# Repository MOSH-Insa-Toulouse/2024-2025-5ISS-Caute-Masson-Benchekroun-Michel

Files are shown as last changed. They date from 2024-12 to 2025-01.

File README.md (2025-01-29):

**Repository structure :**
- [LoRa\_module.ino](LoRa_module.ino) : Smart device code, from the logic for using the gas sensor, to the BLE and LoRa connectivity.
- [Shield\_Gas\_Sensor](Shield_Gas_Sensor) : Design of the Arduino UNO shield for the smart device. See the routing [here](Shield_Gas_Sensor/Acquisition_board_aduino_UNO.kicad_pcb), and the schematic [here](Shield_Gas_Sensor/Acquisition_board_aduino_UNO.kicad_sch)
- [Node-RED](Node-RED) : Node RED application code
- [Documentation](Documentation) : Datasheet of the used components
- [The datasheet](Datasheet_Gas_Sensor.pdf) : Datasheet of our gas sensor
- [The project report](MOSH_Report.pdf) : Report of our smart device project, from the manufacturing of the MOx sensor to the design of our node PCB, sensor conditionner and application

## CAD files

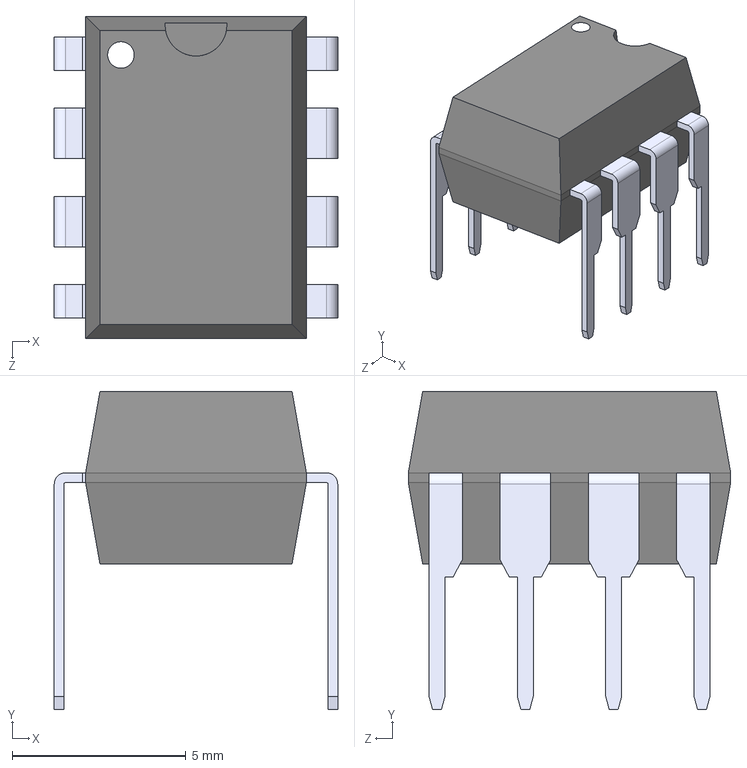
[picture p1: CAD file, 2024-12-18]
Shield_Gas_Sensor/Gas_Sensor_lib/LTC1050ACN8_PBF/LTC1050ACN8_PBF.step
8.15 x 9.14 x 9.27 mm

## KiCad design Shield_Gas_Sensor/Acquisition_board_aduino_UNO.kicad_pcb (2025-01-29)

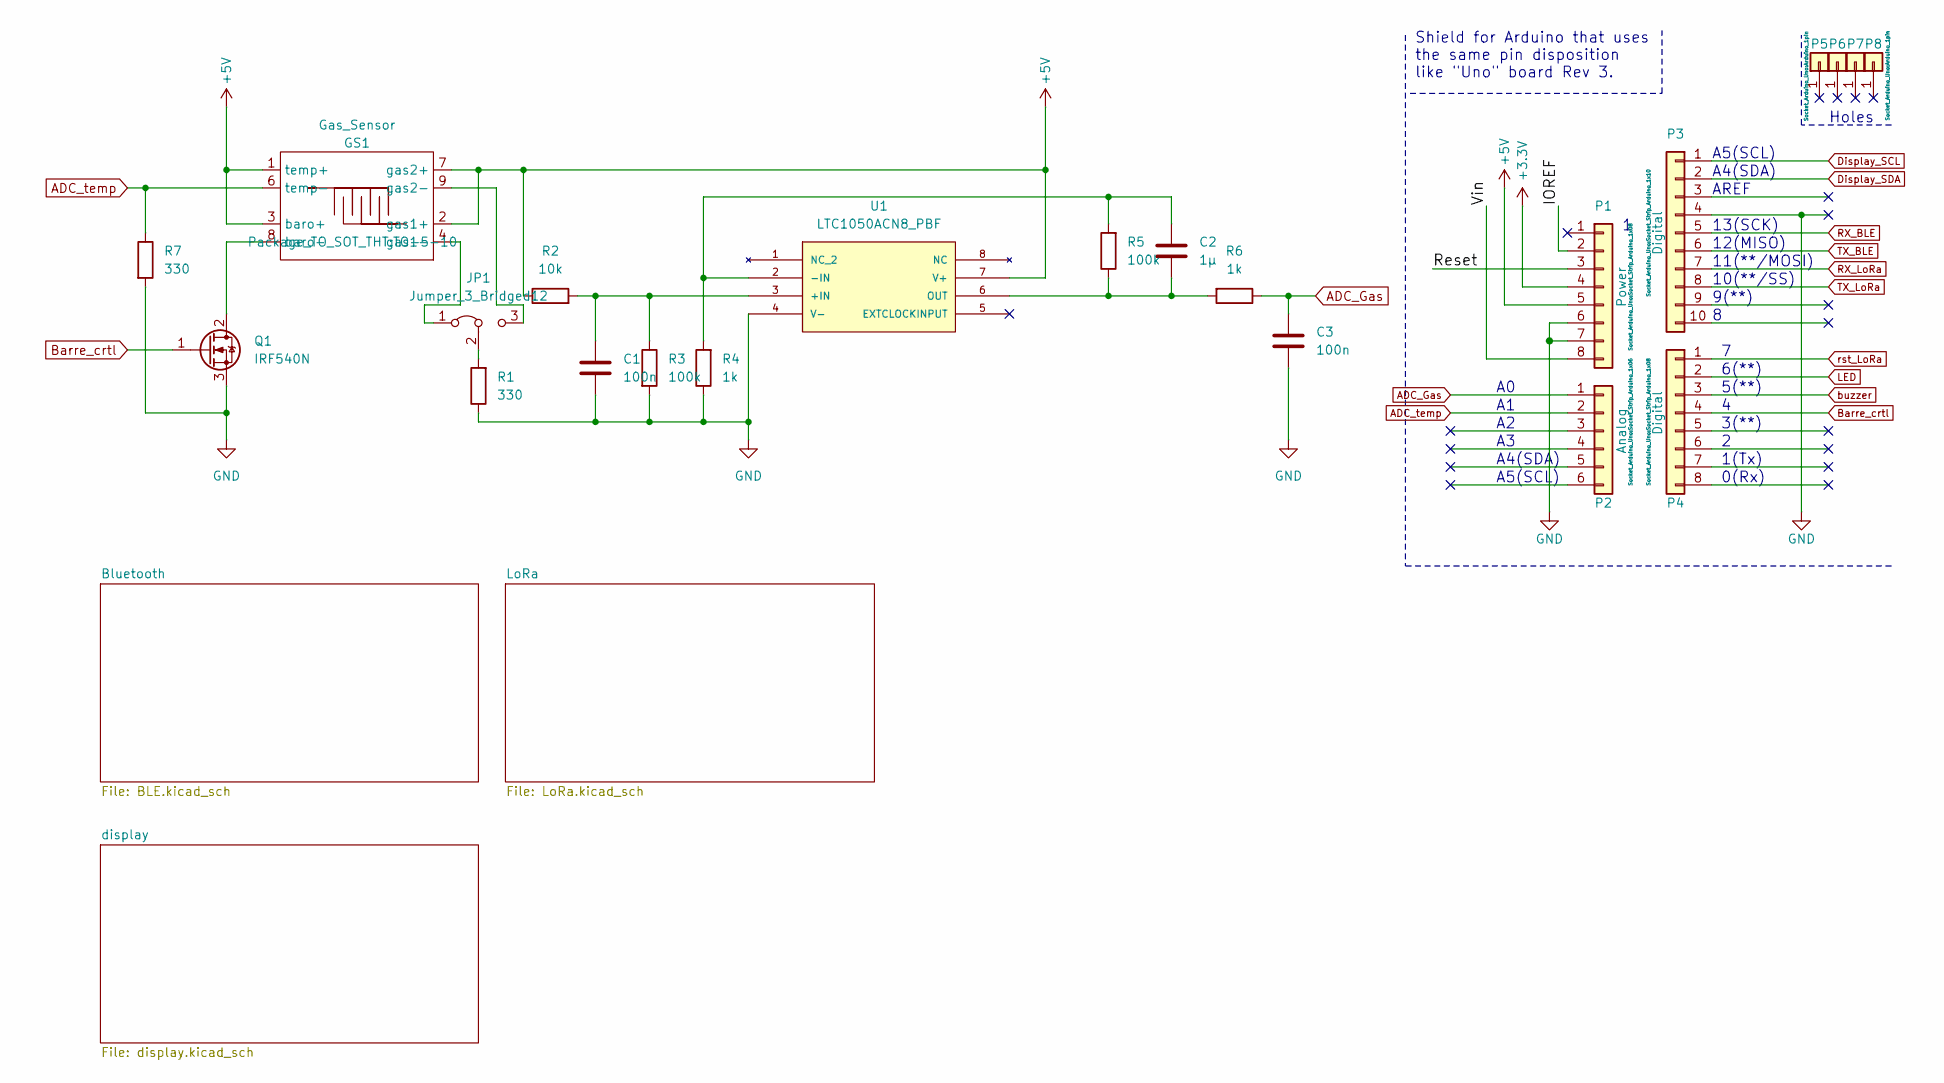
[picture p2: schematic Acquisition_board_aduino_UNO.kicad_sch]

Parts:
C1, C3: 100n; C_Disc_D3.0mm_W1.6mm_P2.50mm
C2: 1µ; C_Rect_L9.0mm_W3.6mm_P7.50mm_MKT
GS1: Gas_Sensor; TO-5-10
JP1: Jumper_3_Bridged12; PinSocket_1x03_P2.54mm_Vertical
P1: Power; Socket_Strip_Arduino_1x08
P2: Analog; Socket_Strip_Arduino_1x06
P3: Digital; Socket_Strip_Arduino_1x10
P4: Digital; Socket_Strip_Arduino_1x08
P5, P6, P7, P8: CONN_01X01; Arduino_1pin
Q1: IRF540N; TO-220-3_Vertical
R1, R7: 330; R_Axial_DIN0204_L3.6mm_D1.6mm_P2.54mm_Vertical
R2: 10k; R_Axial_DIN0204_L3.6mm_D1.6mm_P2.54mm_Vertical
R3, R5: 100k; R_Axial_DIN0204_L3.6mm_D1.6mm_P2.54mm_Vertical
R4, R6: 1k; R_Axial_DIN0204_L3.6mm_D1.6mm_P2.54mm_Vertical
U1: LTC1050ACN8_PBF; DIP-8_W7.62mm; MANUFACTURER_PART_NUMBER ltc1050acn8

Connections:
+3V3: P1.4
+5V: GS1.1 (temp+), GS1.2 (gas1+), GS1.3 (baro+), GS1.7 (gas2+), P1.5, R2.1, U1.7 (V+); also elsewhere on the board
/IOREF: P1.2
/Reset: P1.3
/Vin: P1.8
ADC_Gas: C3.1, P2.1, R6.1
ADC_temp: GS1.6 (temp-), P2.2, R7.1
Barre_crtl: P4.4, Q1.1 (G)
Display_SCL: P3.1; also elsewhere on the board
Display_SDA: P3.2; also elsewhere on the board
GND: C1.2, C3.2, P1.6, P1.7, P3.4, P5.1, P6.1, P7.1, P8.1, Q1.3 (S), R1.1, R3.2, R4.1, R7.2, U1.4 (V-); also elsewhere on the board
LED: P4.2; also elsewhere on the board
unnamed: C1.1, R2.2, R3.1, U1.3 (+IN)
unnamed: C2.1, R4.2, R5.2, U1.2 (-IN)
unnamed: C2.2, R5.1, R6.2, U1.6 (OUT)
unnamed: GS1.4 (gas1-), JP1.1 (A)
unnamed: GS1.8 (baro-), Q1.2 (D)
unnamed: GS1.9 (gas2-), JP1.3 (B)
unnamed: JP1.2 (C), R1.2
RX_BLE: P3.5; also elsewhere on the board
RX_LoRa: P3.7; also elsewhere on the board
TX_BLE: P3.6; also elsewhere on the board
TX_LoRa: P3.8; also elsewhere on the board
buzzer: P4.3; also elsewhere on the board
rst_LoRa: P4.1; also elsewhere on the board

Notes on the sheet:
A5(SCL)
6(**)
10(**/SS)
3(**)
0(Rx)
9(**)
Holes
1(Tx)
Shield for Arduino that uses the same pin disposition like "Uno" board Rev 3.
5(**)
12(MISO)
A4(SDA)
AREF
13(SCK)
11(**/MOSI)

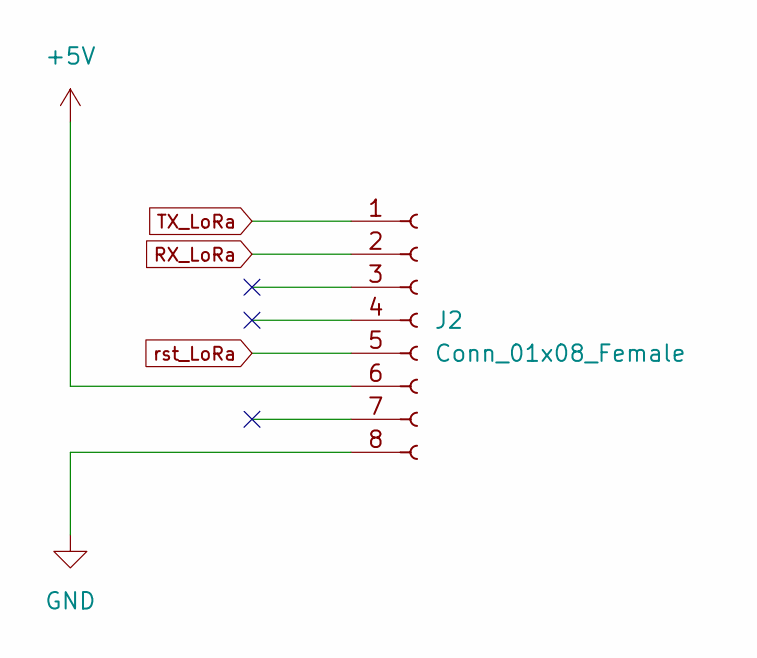
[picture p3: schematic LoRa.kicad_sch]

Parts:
J2: Conn_01x08_Female; PinSocket_1x08_P2.54mm_Vertical

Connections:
+5V: J2.6; also elsewhere on the board
GND: J2.8; also elsewhere on the board
RX_LoRa: J2.2; also elsewhere on the board
TX_LoRa: J2.1; also elsewhere on the board
rst_LoRa: J2.5; also elsewhere on the board

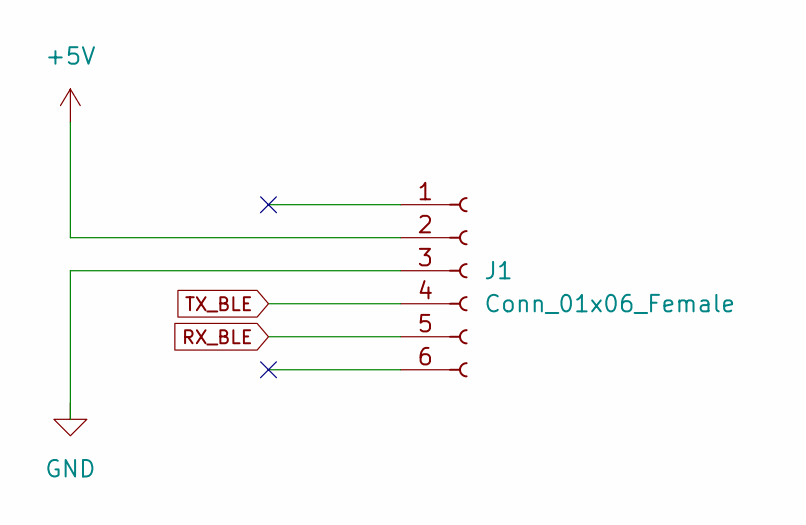
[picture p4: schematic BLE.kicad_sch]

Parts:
J1: Conn_01x06_Female; PinSocket_1x06_P2.54mm_Vertical

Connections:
+5V: J1.2; also elsewhere on the board
RX_BLE: J1.5; also elsewhere on the board
TX_BLE: J1.4; also elsewhere on the board

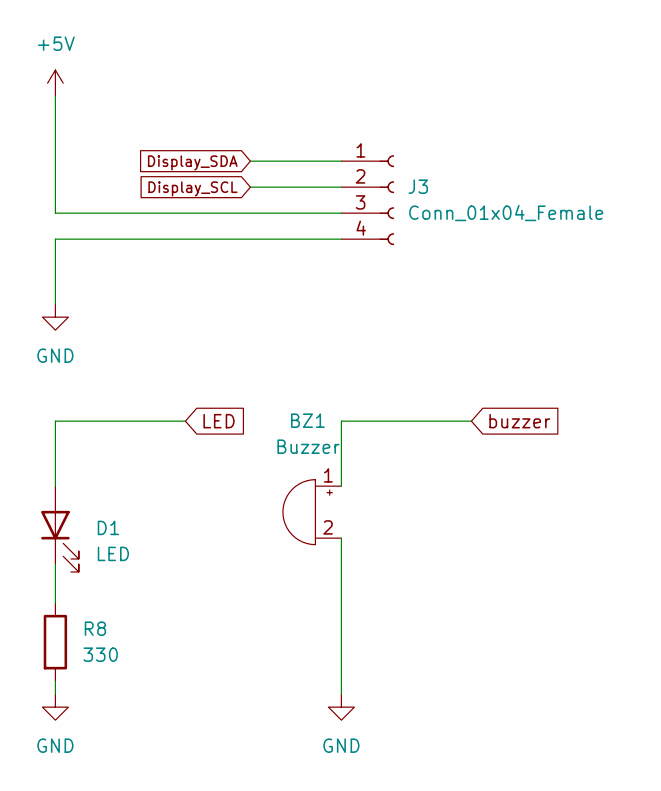
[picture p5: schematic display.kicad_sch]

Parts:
BZ1: Buzzer; Buzzer_TDK_PS1240P02BT_D12.2mm_H6.5mm
D1: LED; LED_D3.0mm
J3: Conn_01x04_Female; PinSocket_1x04_P2.54mm_Vertical
R8: 330; R_Axial_DIN0204_L3.6mm_D1.6mm_P2.54mm_Vertical

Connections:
+5V: J3.3; also elsewhere on the board
Display_SCL: J3.2; also elsewhere on the board
Display_SDA: J3.1; also elsewhere on the board
GND: BZ1.2 (+), J3.4, R8.2; also elsewhere on the board
LED: D1.2 (A); also elsewhere on the board
unnamed: D1.1 (K), R8.1
buzzer: BZ1.1 (-); also elsewhere on the board

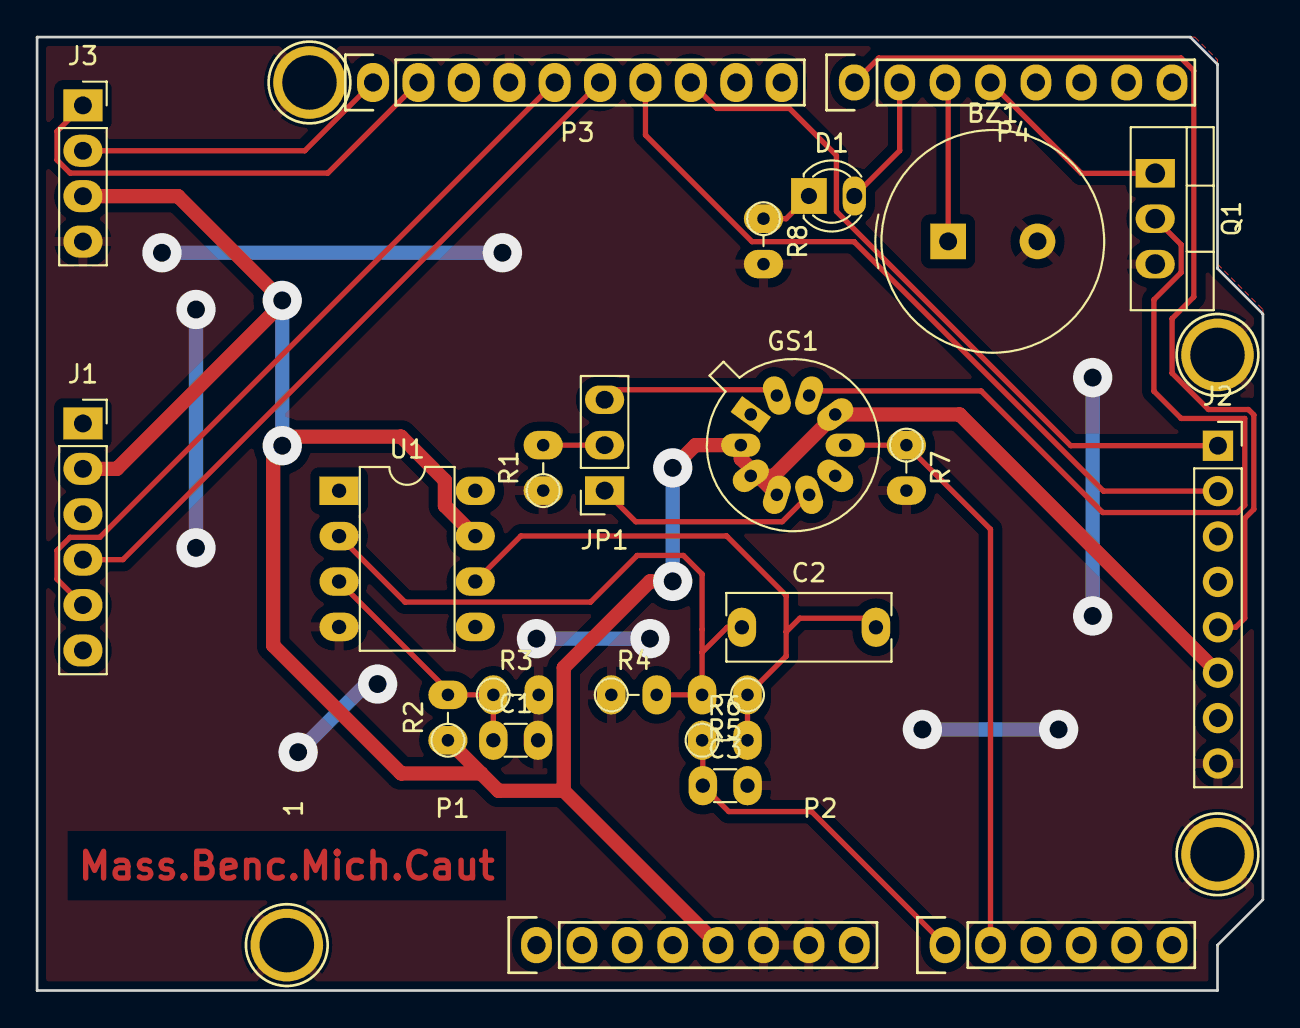
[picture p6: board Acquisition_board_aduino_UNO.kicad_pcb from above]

Board: 2 copper layers, 68.6 x 53.3 mm, 28 parts (0 on the bottom side), 22 nets.

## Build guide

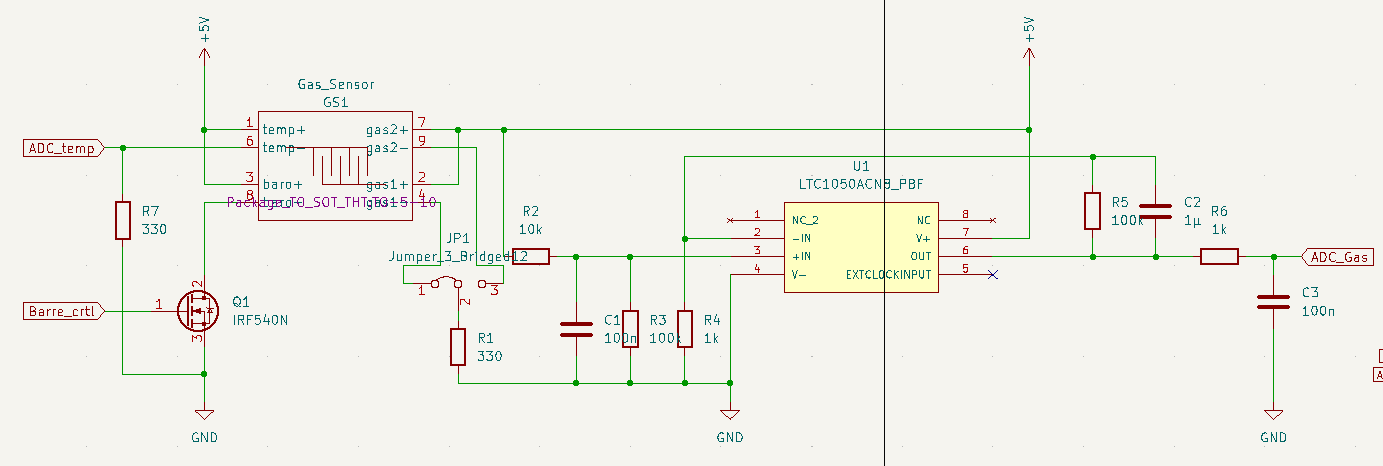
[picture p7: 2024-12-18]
Documentation/montage_trans_impedance.png

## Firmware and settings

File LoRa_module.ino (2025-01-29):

#include <SoftwareSerial.h>
#include <Adafruit_GFX.h>
#include <Adafruit_SSD1306.h>

// Pin definitions for LoRa
#define LORA_RX_PIN 10
#define LORA_TX_PIN 11
SoftwareSerial loraSerial(LORA_RX_PIN, LORA_TX_PIN);

// Pin definitions for Bluetooth HC-05
#define BT_RX_PIN 2
#define BT_TX_PIN 3
SoftwareSerial btSerial(BT_RX_PIN, BT_TX_PIN);

// Pin for gas sensor
#define GAS_SENSOR_PIN A0

// OLED display settings
#define SCREEN_WIDTH 128
#define SCREEN_HEIGHT 32
#define OLED_RESET -1
Adafruit_SSD1306 display(SCREEN_WIDTH, SCREEN_HEIGHT, &Wire, OLED_RESET);

void setup() {
  // Start serial communication
  Serial.begin(9600);
  loraSerial.begin(57600);
  btSerial.begin(9600);
  delay(1000);

  // Initialisation de l'écran OLED
  if (!display.begin(SSD1306_SWITCHCAPVCC, 0x3C)) {
    Serial.println(F("SSD1306 allocation failed"));
    for (;;);
  }

  display.clearDisplay();
  display.setTextSize(1);
  display.setTextColor(SSD1306_WHITE);
  display.setCursor(0, 0);
  display.println(F("Initialisation..."));
  display.display();
  delay(2000);

  // Initialize LoRa
  Serial.println("Starting LoRa RN2483 configuration...");
  pinMode(7, OUTPUT);
  digitalWrite(7, LOW);
  delay(1000);
  digitalWrite(7, HIGH);
  waitForResponse();

  sendCommand("mac reset 868");
  sendCommand("mac set dr 5");
  sendCommand("mac set adr off");
  sendCommand("mac set ar off");
  sendCommand("mac set deveui 0004A30B002109EF");
  sendCommand("mac set appeui 3D75E50F79A51BE9");
  sendCommand("mac set appkey 3BB0E4729335CE0AF5F677CA7F320510");
  sendCommand("mac save");
  sendCommand("mac join otaa");
  waitForResponse();
}

void loop() {
  // Lecture de la valeur brute du capteur de gaz
  int gasValue = analogRead(GAS_SENSOR_PIN);

  // Conversion en tension (en supposant une alimentation de 5V)
  float voltage = gasValue * (5.0 / 1023.0);

  // Affichage sur l'écran OLED
  display.clearDisplay();
  display.setCursor(0, 0);
  display.println(F("Capteur de gaz"));
  display.print(F("Valeur brute: "));
  display.println(gasValue);
  display.print(F("Tension: "));
  display.print(voltage);
  display.println(F(" V"));
  display.display();

  // Send gas value over LoRa
  char hexValue[8];
  sprintf(hexValue, "%04X", gasValue); // Convert to hex
  String payload = "mac tx uncnf 1 " + String(hexValue);
  sendCommand(payload);

  delay(10000); // Wait 10 second for the regeneration of the sensor

  // Send gas value over Bluetooth
  btSerial.print("Gas Sensor Value: ");
  btSerial.println(gasValue);
  Serial.println("Data sent over Bluetooth");
}

void sendCommand(const String& command) {
  loraSerial.println(command);
  Serial.print("Sent: ");
  Serial.println(command);
  waitForResponse();
}

void waitForResponse() {
  while (!loraSerial.available()) {
    delay(10);
  }
  while (loraSerial.available()) {
    String response = loraSerial.readStringUntil('\n');
    Serial.print("Received: ");
    Serial.println(response);
  }
}

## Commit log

2024-12-17 lora test do not work
    [ampli_Gas_Senor.kicad_pcb, ampli_Gas_Senor.kicad_sch]
2024-12-17 Create Node-RED flows
2024-12-18 schematic finished
    [Acquisition_board_aduino_UNO.kicad_pcb, Acquisition_board_aduino_UNO.kicad_sch, BLE.kicad_sch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]
2025-01-29 routing n schematic
    [Acquisition_board_aduino_UNO.kicad_pcb, Acquisition_board_aduino_UNO.kicad_sch, BLE.kicad_sch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]
2025-01-29 Add the code for the Arduino

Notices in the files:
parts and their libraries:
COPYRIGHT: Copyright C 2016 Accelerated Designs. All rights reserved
